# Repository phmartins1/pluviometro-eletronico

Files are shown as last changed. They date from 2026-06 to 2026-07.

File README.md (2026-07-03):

# Pluviômetro Eletrônico

Projeto de um **pluviômetro eletrônico** utilizando **sensores piezoelétricos**.

* **Hardware**: Circuito elétrico integrado com um microcontrolador ESP32
* **Firmware**: Captura dos dados e transmissão via protocolo MQTT, operando sobre conexão WiFi
* **Nuvem**: Cálculo do volume de chuva (mm e mm/h) a partir do sinal cru

## Estrutura do Repositório

```
pluviometro-eletronico/
├── checkpoints-anteriores/   # Material desenvolvido em checkpoints anteriores (ultrapassado)
├── firmware/                 # Firmware de leitura dos piezos e transmissão de dados (ESP32)
├── hardware/                 # Esquemáticos elétricos do pluviômetro
├── telemetria/               # Simulador da telemetria
├── .gitignore
└── README.md
```

## Arquitetura: mínimo na placa, cálculo na nuvem

A abordagem atual divide o trabalho assim: **a placa só mede, a nuvem interpreta**.

O ESP32 lê os 4 piezos, preenche um buffer de `N` amostras por canal e publica os
buffers **brutos** (tensão em V) junto com o tempo real de coleta e a geometria do
sensor. Ele não calcula integral, mm, mm/h, RMS nem picos. Toda essa interpretação
acontece na nuvem (ThingsBoard / processamento), que guarda o histórico e a forma de
onda completa.

Vantagens:

- **Recalibração livre**: como a nuvem tem o sinal cru de todo o histórico, dá para
  mudar a constante de calibração ou o próprio algoritmo e reavaliar tudo, sem
  reprogramar o sensor.
- **Placa mais simples e econômica**: sem timer, sem acumuladores, sem multiplicação
  por calibração. Entre coletas o ESP poderia até entrar em deep sleep.
- **Flexibilidade**: qualquer métrica nova (filtragem de artefatos, contagem de
  impactos, detecção de eventos) é só uma consulta sobre os dados já guardados.

### O que a placa envia

A cada buffer cheio, o ESP publica um JSON via MQTT:

```json
{
  "ident": "pluviometro_teste",
  "T": 1.395,
  "n": 300,
  "area_maior_cm2": 144.0,
  "area_menor_cm2": 47.6,
  "buf_A0": [0.0, 0.0, 0.142, ...],
  "buf_A1": [...],
  "buf_A2": [...],
  "buf_A3": [...]
}
```

| Campo | O que é |
|---|---|
| `ident` | identificador do device (usado pelo stream flespi -> ThingsBoard) |
| `T` | duração **real** da coleta dos `N` pontos (s), medida com `millis()` |
| `n` | amostras por canal |
| `area_maior_cm2` | área das faces maiores (A0, A2) |
| `area_menor_cm2` | área das faces menores (A1, A3) |
| `buf_A0..buf_A3` | buffers brutos de tensão (V) de cada piezo |

> O payload tem alguns KB (4 buffers de `N` floats). No firmware é preciso aumentar o
> buffer interno do PubSubClient (`setBufferSize`), senão a mensagem é truncada.

## Precisão por área: combinando os 4 piezos

O pluviômetro tem 4 faces piezoelétricas de dois tamanhos:

- Faces **maiores** (A0, A2): 144 cm² cada.
- Faces **menores** (A1, A3): 47,6 cm² cada.
- Área total de captação: `2*144 + 2*47,6 = 383,2 cm²`.

Cada piezo é um coletor de área conhecida. O integral `S` de cada face é proporcional à
quantidade de água que bateu nela, ou seja, proporcional à taxa de chuva **vezes** a
área daquela face. Uma face maior recebe mais gotas e gera um sinal proporcionalmente
maior (no simulador isso aparece como o fator `AREA_MENOR / AREA_MAIOR`, que reduz o
sinal das faces menores na proporção da área).

Para ganhar precisão, a nuvem trata os 4 piezos como **um único coletor maior**: soma os
integrais e divide pela área total. Combinar mais área é o mesmo que ter um pluviômetro
maior, então o ruído estatístico (pouca gota numa janela curta) se cancela e a lâmina
(mm) fica mais estável do que a de um piezo isolado.

Cálculo na nuvem, por reporte:

```
# 1. integral de cada face a partir do buffer (mesma fórmula de antes, agora na nuvem)
S_i = (soma das tensões do buffer_i) * T / n        [V·s]

# 2. combina as 4 faces como um coletor de área total
S_total = S_A0 + S_A1 + S_A2 + S_A3
A_total = 383,2 cm²

# 3. lâmina caída no período (a calibração c embute a área e a sensibilidade)
lamina_mm = c * S_total

# ou, deixando a área explícita (densidade de sinal por área):
densidade   = S_total / A_total        [V·s/cm²]
lamina_mm   = c_area * densidade
```

A ponderação por área é exatamente essa divisão pela área total: as faces maiores pesam
mais, as menores pesam menos, na proporção em que captam chuva. O acumulado (mm) e as
intensidades (mm/h) saem de somar `S_total` sobre diferentes janelas de tempo.

## Simulador

[`telemetria/simulador-telemetria.py`](telemetria/simulador-telemetria.py) reproduz a telemetria da
abordagem atual: gera os buffers brutos dos 4 piezos (com sinal proporcional à área de
cada face) e publica no broker no mesmo formato do firmware. Útil para desenvolver e
testar o processamento na nuvem sem o hardware.

```
pip install paho-mqtt
python simulador-telemetria.py
```

## Segurança

Credenciais sensíveis (Rede WiFi, Broker MQTT) não são incluídas no repositório.

Utilize o arquivo [`firmware/exemplo_secrets.h`](firmware/exemplo_secrets.h) como base para criar seu próprio `secrets.h`.

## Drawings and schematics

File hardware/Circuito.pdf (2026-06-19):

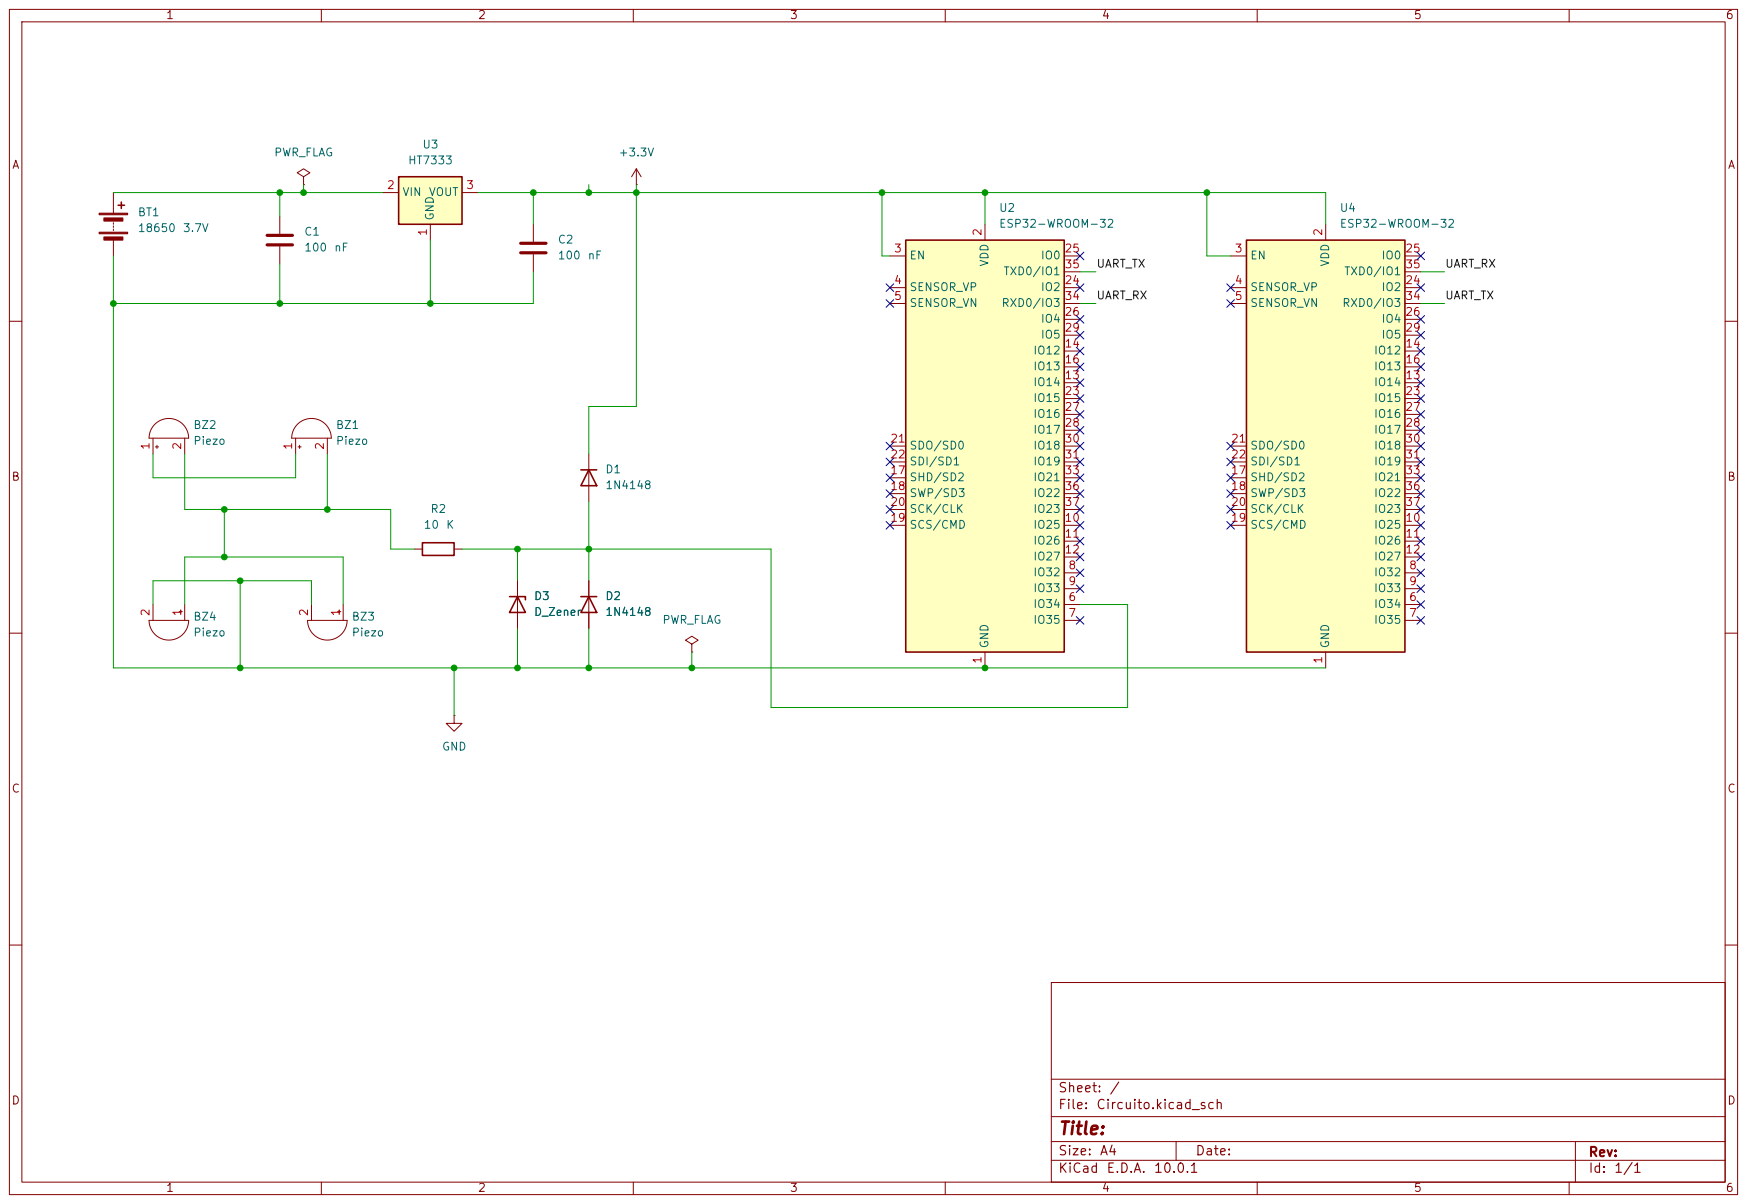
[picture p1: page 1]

Size: A4 | Rev:
KiCad E.D.A. 10.0.1 | Id: 1/1

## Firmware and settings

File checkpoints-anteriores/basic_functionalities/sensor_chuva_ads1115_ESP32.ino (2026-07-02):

/*
   OBJETIVO:
   - Ler tensão do piezo ao longo do tempo
   - Detectar impactos de chuva
   - Medir:
       * Pico de tensão
       * Energia RMS
       * Taxa de impactos
       * Integral do sinal (S) -> base do cálculo de chuva (mm e mm/h)
   - Publicar a telemetria no broker MQTT (ThingsBoard / flespi)

   OBS:
   ligação é single-ended (0V a 3.3V),
   o sinal negativo é cortado pelos diodos.
   detectar PULSOS/IMPACTOS.

   DIVISÃO DE RESPONSABILIDADES (ver calculo_chuva_piezo_thingsboard.md):
   - O ESP32 apenas MEDE: integra o sinal (S, em V·s) e acumula ~10 s.
   - O ThingsBoard INTERPRETA: aplica a constante de calibração c e agrega
     para gerar acumulado (mm), intensidade real (mm/h) e instantânea (mm/h).
   Por isso o ESP NÃO multiplica por c nem calcula mm/h: manda só o S cru.
*/

// Wifi Base
#include <WiFi.h>
// Biblioteca MQTT
#include <PubSubClient.h>
// Montar JSON
#include <ArduinoJson.h>
#include <Wire.h>
#include <Adafruit_ADS1X15.h>
// Configurações (credenciais de WiFi e broker)
#include "secrets.h"

Adafruit_ADS1115 ads;

// CONFIGURAÇÕES

// Pinos I2C no ESP32
#define SDA_PIN 21
#define SCL_PIN 22
#define CHANNEL 0
#define CHANNEL_2 2

const int SAMPLE_RATE = 860;        // máximo ADS1115
const int BUFFER_SIZE = 300;        // ~348 ms de janela (N amostras)
const float THRESHOLD = 0.03;       // 30mV (mais sensível) podemos alterar aqui caso precisarmos de aumentar/diminuir a sensibilidade
const float ADC_LSB = 0.000125;     // GAIN_ONE = 0.125mV/bit
const float NOISE_FLOOR = 0.003;    // abaixo disso é ruído, vira 0

float samplesA0[BUFFER_SIZE];       //Buffer leityra canal 1
float samplesA2[BUFFER_SIZE];       //Buffer leityra canal 2

// Conexões
const unsigned long TIMEOUT_CONEXAO = 20000;
const unsigned long INTERVALO_VERIFICACAO = 10000;
unsigned long ultimaVerificacao = 0;

WiFiClient clienteWiFi;
PubSubClient clienteMQTT(clienteWiFi);

// Intervalo de reporte: acumula ~10 s e publica o S somado (ver doc, seção 7).
const unsigned long INTERVALO_PUBLICACAO = 10000;

// Acumuladores do intervalo de reporte (Entrada A0)
float    S_reportA0        = 0;   // soma dos S de cada janela (V·s) -> principal
uint32_t impactos_reportA0 = 0;   // contagem de impactos no intervalo
float    pico_reportA0     = 0;   // maior tensão no intervalo (diagnóstico)
double   somaQuad_reportA0 = 0;   // soma dos quadrados (para o RMS do intervalo)
uint32_t nAmostras_reportA0 = 0;  // total de amostras lidas no intervalo
unsigned long t_ini_reportA0 = 0; // marca o início do intervalo de reporte


// Acumuladores do intervalo de reporte (Entrada A2)
float    S_reportA2        = 0;   // soma dos S de cada janela (V·s) -> principal
uint32_t impactos_reportA2 = 0;   // contagem de impactos no intervalo
float    pico_reportA2     = 0;   // maior tensão no intervalo (diagnóstico)
double   somaQuad_reportA2 = 0;   // soma dos quadrados (para o RMS do intervalo)
uint32_t nAmostras_reportA2 = 0;  // total de amostras lidas no intervalo
unsigned long t_ini_reportA2 = 0; // marca o início do intervalo de reporte


// FUNÇÕES

// Calcula RMS (Root Mean Square / valor quadrático médio)
// Mede a energia média do sinal na janela de amostras.
// Útil para estimar intensidade geral da chuva:
// - RMS baixo = pouco impacto / chuva fraca
// - RMS alto = muitos impactos / chuva forte
//
// Etapas:
// 1. Eleva cada amostra ao quadrado
// 2. Soma tudo
// 3. Divide pelo número de amostras
// 4. Aplica raiz quadrada para voltar à unidade em volts
// Calcula RMS
float calculateRMS(float *buffer, int size) {
  double sum = 0;

  for (int i = 0; i < size; i++) {
    sum += buffer[i] * buffer[i];
  }

  return sqrt(sum / size);
}

// Pico máximo
// Calcula o pico máximo de tensão na janela de amostras
// Mede o maior valor detectado pelo sensor no período analisado.
// Útil para identificar o impacto mais forte (ex: gota maior ou batida mais intensa).
//
// Etapas:
// 1. Percorre todas as amostras
// 2. Compara cada valor com o maior já encontrado
// 3. Atualiza se encontrar um valor maior
// 4. Retorna o maior pico de tensão registrado
float calculatePeak(float *buffer, int size) {
  float peak = 0;

  for (int i = 0; i < size; i++) {
    if (buffer[i] > peak) {
      peak = buffer[i];
    }
  }

  return peak;
}

// Soma linear das tensões da janela (Σ|vi|).
// É a base do integral S: somaV / N é a tensão média, e multiplicada pelo
// tempo da janela vira a "área" sob o sinal (V·s).
float sumVoltage(float *buffer, int size) {
  float soma = 0;

  for (int i = 0; i < size; i++) {
    soma += buffer[i];
  }

  return soma;
}

/// Conta quantos impactos (gotas/pulsos) ocorreram na janela de amostras.
// Um impacto é registrado quando o sinal ultrapassa o threshold definido.
//
// Cooldown (período morto):
// Após detectar um impacto, o sistema ignora algumas leituras por alguns ms
// para evitar contar várias oscilações da mesma gota como impactos diferentes.
//
// Etapas:
// 1. Percorre todas as amostras
// 2. Verifica se está em cooldown
// 3. Se estiver, ignora a leitura
// 4. Se o valor passar do threshold, conta um novo impacto
// 5. Ativa cooldown para evitar múltiplas contagens do mesmo evento
int countImpacts(float *buffer, int size, float threshold) {
  int count = 0;
  int cooldown = 0;

  for (int i = 0; i < size; i++) {

    // Ignora leituras durante período morto
    if (cooldown > 0) {
      cooldown--;
      continue;
    }

    // Novo impacto
    if (buffer[i] > threshold) {
      count++;
      cooldown = 8; // ~9 ms em 860 SPS
    }
  }

  return count;
}

// CONEXÃO WIFI
bool conectarWiFi()
{
  Serial.print("Conectando à rede: ");
  Serial.println(WIFI_SSID);

  WiFi.mode(WIFI_STA);
  WiFi.begin(WIFI_SSID, WIFI_PASSWORD);

  unsigned long inicio = millis();
  while (WiFi.status() != WL_CONNECTED)
  {
    if (millis() - inicio > TIMEOUT_CONEXAO)
    {
      Serial.println("\nFalha: tempo de conexão esgotado.");
      return false;
    }
    delay(500);
    Serial.print(".");
  }

  Serial.println("\nConexão estabelecida!");
  Serial.print("Endereço IP: ");
  Serial.println(WiFi.localIP());
  Serial.print("RSSI (intensidade do sinal): ");
  Serial.print(WiFi.RSSI());
  Serial.println(" dBm");
  return true;
}

// CONEXÃO BROKER MQTT
void conectarBrokerMQTT()
{
  if (WiFi.status() != WL_CONNECTED)
    return;

  Serial.println("Conectando ao Broker MQTT...");

  unsigned long inicio = millis();
  while (!clienteMQTT.connected())
  {
    if (millis() - inicio > TIMEOUT_CONEXAO)
    {
      Serial.println("\nFalha: tempo de conexão ao Broker MQTT esgotado.");
      return;
    }

    char IDCliente[50];
    sprintf(IDCliente, "PEC-Pluviometro-%06X", (uint32_t)ESP.getEfuseMac());

    if (clienteMQTT.connect(IDCliente, TOKEN_BROKER, ""))
    {
      Serial.println("Conectado ao Broker MQTT.");
      return;
    }
    else
    {
      Serial.print("Falha, rc=");
      Serial.println(clienteMQTT.state()); // diagnostico de falha
      delay(2000);
    }
  }
}

// verificar e reconectar se necessário
void verificarConexao()
{
  if (WiFi.status() != WL_CONNECTED)
  {
    Serial.println("Conexão WiFi perdida. Tentando reconectar...");
    WiFi.disconnect();
    conectarWiFi();
  }
  else
  {
    Serial.print("Wi-Fi ativo | IP: ");
    Serial.print(WiFi.localIP());
    Serial.print(" | RSSI: ");
    Serial.print(WiFi.RSSI());
    Serial.println(" dBm");
  }

  if (!clienteMQTT.connected())
  {
    Serial.println("Conexão ao Broker MQTT perdida. Tentando reconectar...");
    clienteMQTT.disconnect();
    conectarBrokerMQTT();
  }
}

// Monta e publica a telemetria do intervalo de reporte.
// Campos (ver doc, seção 4):
//   S        -> integral acumulado do intervalo (V·s)  [PRINCIPAL]
//   T        -> duração real do intervalo (s)
//   impactos -> contagem de impactos no intervalo
//   pico     -> maior tensão no intervalo (diagnóstico)
//   rms      -> RMS do sinal no intervalo (diagnóstico)
// IMPORTANTE: envia o INCREMENTO do intervalo (não um total que só cresce),
// para o SUM do ThingsBoard funcionar direto.
void publicarTelemetria(float S, float T, uint32_t impactos, float pico, float rms)
{
  JsonDocument doc;

  // O 'ident' e obrigatorio: o stream flespi -> ThingsBoard usa ele para
  // identificar o device. Sem ident a mensagem nao chega no ThingsBoard.
  doc["ident"] = "pluviometro_teste";
  doc["S"] = S;
  doc["T"] = T;
  doc["impactos"] = impactos;
  doc["pico"] = pico;
  doc["rms"] = rms;

  String payload;
  serializeJson(doc, payload);

  if (clienteMQTT.connected())
  {
    bool publicado = clienteMQTT.publish(TOPICO_MQTT, payload.c_str());
    if (publicado)
      Serial.println("Publicado: " + payload);
    else
      Serial.println("Falha ao publicar");
  }
  else
  {
    Serial.println("Sem conexão MQTT, telemetria não enviada: " + payload);
  }
}

// SETUP
void setup() {
  Serial.begin(115200);
  delay(1000);

  Wire.begin(SDA_PIN, SCL_PIN);

  if (!ads.begin()) {
    Serial.println("ERRO: ADS1115 não encontrado!");
    while (1);
  }

  ads.setGain(GAIN_ONE);                  // até 4.096V
  ads.setDataRate(RATE_ADS1115_860SPS);  // máxima velocidade

  Serial.println("\nInicializando módulo Wi-Fi");
  conectarWiFi();

  clienteMQTT.setServer(BROKER_MQTT, PORTA_MQTT);
  conectarBrokerMQTT();

  Serial.println("Sistema iniciado");
  t_ini_reportA0 = millis();
  t_ini_reportA2 = millis();
}

// LOOP
void loop() {

  // --- coleta uma janela cronometrada de N amostras ---
  unsigned long t0 = millis();
  for (int i = 0; i < BUFFER_SIZE; i++) {

    //int16_t raw = ads.readADC_SingleEnded(CHANNEL);
    int16_t rawA0 = ads.readADC_SingleEnded(CHANNEL);
    int16_t rawA2 = ads.readADC_SingleEnded(CHANNEL_2);

    // Converte para volts
    //float voltage = raw * ADC_LSB;
    float voltageA0 = rawA0 * ADC_LSB;
    float voltageA2 = rawA2 * ADC_LSB;


    // Remove ruído muito baixo
    //if (voltage < NOISE_FLOOR) voltage = 0;
    if (voltageA0 < NOISE_FLOOR) voltageA0 = 0;
    if (voltageA2 < NOISE_FLOOR) voltageA2 = 0;

    //samples[i] = voltage;
    samplesA0[i] = voltageA0;
    samplesA2[i] = voltageA2;

    // ADS1115 já limita pela taxa interna
    delay(1);
  }
  float T_janela = (millis() - t0) / 1000.0;  // duração REAL da janela (s)

  // --- análises da janela ---
  //float somaV = sumVoltage(samples, BUFFER_SIZE);
  //float peak = calculatePeak(samples, BUFFER_SIZE);
  //int impacts = countImpacts(samples, BUFFER_SIZE, THRESHOLD);
  float peakA0 = calculatePeak(samplesA0, BUFFER_SIZE);
  float peakA2 = calculatePeak(samplesA2, BUFFER_SIZE);

  int impactsA0 = countImpacts(samplesA0, BUFFER_SIZE, THRESHOLD);
  int impactsA2 = countImpacts(samplesA2, BUFFER_SIZE, THRESHOLD);

  float somaVA0 = sumVoltage(samplesA0, BUFFER_SIZE);
  float somaVA2 = sumVoltage(samplesA2, BUFFER_SIZE);

  // Integral da janela: S = (tensão média) * tempo da janela = somaV * T / N
  //float S_janela = somaV * T_janela / BUFFER_SIZE;
  float S_janelaA0 = somaVA0 * T_janela / BUFFER_SIZE;
  float S_janelaA2 = somaVA2 * T_janela / BUFFER_SIZE;

  // --- acúmulo no intervalo de reporte ---
  S_reportA0 += S_janelaA0;
  S_reportA2 += S_janelaA2;

  impactos_reportA0 += impactsA0;
  impactos_reportA2 += impactsA2;

  if (peakA0 > pico_reportA0) pico_reportA0 = peakA0;
  for (int i = 0; i < BUFFER_SIZE; i++) {
    somaQuad_reportA0 += (double)samplesA0[i] * samplesA0[i];
  }
  nAmostras_reportA0 += BUFFER_SIZE;

  if (peakA2 > pico_reportA2) pico_reportA2 = peakA2;
  for (int i = 0; i < BUFFER_SIZE; i++) {
    somaQuad_reportA2 += (double)samplesA2[i] * samplesA2[i];
  }
  nAmostras_reportA2 += BUFFER_SIZE;

  // Classificação de chuva (exemplo simples; refinar futuramente)
  const char* chuva;
  int impacts = (impactsA0 + impactsA2);
  if (impacts < 1)        chuva = "Sem Chuva";
  else if (impacts < 8)   chuva = "Chuva Fraca";
  else if (impacts < 20)  chuva = "Chuva Moderada";
  else                    chuva = "Chuva Forte";

  // SERIAL MONITOR (diagnóstico da janela)
  Serial.println("--------------------------------");

  Serial.print("Pico Piezo 1: ");      Serial.print(peakA0, 4);      Serial.println(" V");
  Serial.print("Pico Piezo 2: ");      Serial.print(peakA2, 4);      Serial.println(" V");


  Serial.print("Impactos Somados (Piezo 1 + Piezo 2): ");  Serial.println(impacts);

  Serial.print("S janela Piezo 1: ");  Serial.print(S_janelaA0, 6);  Serial.println(" V.s");
  Serial.print("S janela Piezo 2: ");  Serial.print(S_janelaA2, 6);  Serial.println(" V.s");

  Serial.print("Status: ");    Serial.println(chuva);

  // --- a cada INTERVALO_PUBLICACAO, publica o acumulado e zera ---
  if (millis() - t_ini_reportA0 >= INTERVALO_PUBLICACAO) {
    float T_reportA0 = (millis() - t_ini_reportA0) / 1000.0;
    float rms_reportA0 = nAmostras_reportA0 > 0
                         ? sqrt(somaQuad_reportA0 / nAmostras_reportA0)
                         : 0;
               
    publicarTelemetria(S_reportA0, T_reportA0, impactos_reportA0, pico_reportA0, rms_reportA0);
    

    // zera os acumuladores do próximo intervalo
    S_reportA0 = 0;
    impactos_reportA0 = 0;
    pico_reportA0 = 0;
    somaQuad_reportA0 = 0;
    nAmostras_reportA0 = 0;
    t_ini_reportA0 = millis();

  }

  if (millis() - t_ini_reportA2 >= INTERVALO_PUBLICACAO) {
    float T_reportA2 = (millis() - t_ini_reportA2) / 1000.0;
    float rms_reportA2 = nAmostras_reportA2 > 0
                         ? sqrt(somaQuad_reportA2 / nAmostras_reportA2)
                         : 0;

    publicarTelemetria(S_reportA2, T_reportA2, impactos_reportA2, pico_reportA2, rms_reportA2);

    
    S_reportA2 = 0;
    impactos_reportA2 = 0;
    pico_reportA2 = 0;
    somaQuad_reportA2 = 0;
    nAmostras_reportA2 = 0;
    t_ini_reportA2 = millis();
  }     

  // Reconexão periódica (não bloqueia a coleta)
  if (millis() - ultimaVerificacao >= INTERVALO_VERIFICACAO) {
    ultimaVerificacao = millis();
    verificarConexao();
  }

  clienteMQTT.loop();
}

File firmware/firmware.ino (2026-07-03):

/*
   OBJETIVO: O ESP32 realiza as medições brutas e envia via MQTT.
   Os cálculos matemáticos e geração do volume total ocorrem na Rule Chain.
*/

// Wifi Base
#include <WiFi.h>
// Biblioteca MQTT
#include <PubSubClient.h>
// Montar JSON
#include <ArduinoJson.h>
#include <Wire.h>
#include <Adafruit_ADS1X15.h>
// Configurações (credenciais de WiFi e broker)
#include "secrets.h"

Adafruit_ADS1115 ads;

// CONFIGURAÇÕES
#define SDA_PIN 21
#define SCL_PIN 22
#define CHANNEL 0
#define CHANNEL_1 1
#define CHANNEL_2 2
#define CHANNEL_3 3

const float JANELA_SEGUNDOS = 5.0;
const int   BUFFER_SIZE = 300;        // N amostras por canal antes de publicar
const float ADC_LSB     = 0.000125;   // GAIN_ONE = 0,125 mV/bit
const float NOISE_FLOOR = 0.003;      // abaixo disso é ruído, vira 0 (V)


// Buffers de leitura (tensão em V)
float samples_PiezoA0[BUFFER_SIZE];
float samples_PiezoA1[BUFFER_SIZE];
float samples_PiezoA2[BUFFER_SIZE];
float samples_PiezoA3[BUFFER_SIZE];

const uint16_t MQTT_BUFFER_SIZE = 20480;

// Conexões
const unsigned long TIMEOUT_CONEXAO = 20000;
const unsigned long INTERVALO_VERIFICACAO = 10000;
unsigned long ultimaVerificacao = 0;

WiFiClient clienteWiFi;
PubSubClient clienteMQTT(clienteWiFi);

bool conectarWiFi() {
  Serial.print("Conectando à rede: ");
  Serial.println(WIFI_SSID);
  WiFi.mode(WIFI_STA);
  WiFi.begin(WIFI_SSID, WIFI_PASSWORD);

  unsigned long inicio = millis();
  while (WiFi.status() != WL_CONNECTED) {
    if (millis() - inicio > TIMEOUT_CONEXAO) {
      Serial.println("\nFalha: tempo de conexão esgotado.");
      return false;
    }
    delay(500);
    Serial.print(".");
  }
  Serial.println("\nConexão estabelecida!");
  return true;
}

void conectarBrokerMQTT() {
  if (WiFi.status() != WL_CONNECTED) return;
  Serial.println("Conectando ao ThingsBoard via MQTT...");

  unsigned long inicio = millis();
  while (!clienteMQTT.connected()) {
    if (millis() - inicio > TIMEOUT_CONEXAO) {
      Serial.println("\nFalha: tempo de conexão esgotado.");
      return;
    }

    char IDCliente[50];
    sprintf(IDCliente, "ESP32-Pluviometro-%06X", (uint32_t)ESP.getEfuseMac());

    if (clienteMQTT.connect(IDCliente, TOKEN_BROKER, "")) {
      Serial.println("Conectado ao ThingsBoard com sucesso!");
      return;
    } else {
      Serial.print("Falha na conexão, rc=");
      Serial.println(clienteMQTT.state());
      delay(2000);
    }
  }
}

void verificarConexao() {
  if (WiFi.status() != WL_CONNECTED) {
    WiFi.disconnect();
    conectarWiFi();
  }
  if (!clienteMQTT.connected()) {
    conectarBrokerMQTT();
  }
}

void publicarBuffers(float T) {
  JsonDocument doc;
  doc["T"] = T;
  doc["n"] = BUFFER_SIZE;

  JsonArray a0 = doc["buf_A0"].to<JsonArray>();
  JsonArray a1 = doc["buf_A1"].to<JsonArray>();
  JsonArray a2 = doc["buf_A2"].to<JsonArray>();
  JsonArray a3 = doc["buf_A3"].to<JsonArray>();

  for (int i = 0; i < BUFFER_SIZE; i++) {
    a0.add(serialized(String(samples_PiezoA0[i], 4)));
    a1.add(serialized(String(samples_PiezoA1[i], 4)));
    a2.add(serialized(String(samples_PiezoA2[i], 4)));
    a3.add(serialized(String(samples_PiezoA3[i], 4)));
  }

  String payload;
  serializeJson(doc, payload);

  if (clienteMQTT.connected()) {
    bool publicado = clienteMQTT.publish(TOPICO_MQTT, payload.c_str());
    if (publicado) {
      Serial.printf("Enviado: T=%.3f s | %u bytes\n", T, (unsigned)payload.length());
    } else {
      Serial.printf("Falha ao enviar. %u bytes\n", (unsigned)payload.length());
    }
  } else {
    Serial.println("Sem conexão MQTT. Dados perdidos.");
  }
}

void setup() {
  Serial.begin(115200);
  delay(1000);
  Wire.begin(SDA_PIN, SCL_PIN);
  Wire.setClock(400000);

  if (!ads.begin()) {
     Serial.println("ERRO: ADS1115 não encontrado!");
     while (1);
  }

  ads.setGain(GAIN_ONE);          
  ads.setDataRate(RATE_ADS1115_860SPS);  

  conectarWiFi();
  clienteMQTT.setBufferSize(MQTT_BUFFER_SIZE);
  clienteMQTT.setServer(BROKER_MQTT, PORTA_MQTT);
  conectarBrokerMQTT();

  Serial.println("Sistema Pronto.");
}

void loop() {
  unsigned long t0 = micros();
  
  // 5 segundos / 300 amostras = 16666 us por ciclo
  const uint32_t INTERVALO_US = (uint32_t)(JANELA_SEGUNDOS * 1000000.0 / BUFFER_SIZE);
  uint32_t proximaLeitura = micros();

  for (int i = 0; i < BUFFER_SIZE; ) {
    if ((int32_t)(micros() - proximaLeitura) >= 0) {
      
      // Realiza a leitura sequencial nos 4 canais
      int16_t raw_PiezoA0 = ads.readADC_SingleEnded(CHANNEL);
      int16_t raw_PiezoA1 = ads.readADC_SingleEnded(CHANNEL_1);
      int16_t raw_PiezoA2 = ads.readADC_SingleEnded(CHANNEL_2);
      int16_t raw_PiezoA3 = ads.readADC_SingleEnded(CHANNEL_3);

      float v0 = raw_PiezoA0 * ADC_LSB;
      float v1 = raw_PiezoA1 * ADC_LSB;
      float v2 = raw_PiezoA2 * ADC_LSB;
      float v3 = raw_PiezoA3 * ADC_LSB;

      samples_PiezoA0[i] = (v0 < NOISE_FLOOR) ? 0.0f : v0;
      samples_PiezoA1[i] = (v1 < NOISE_FLOOR) ? 0.0f : v1;
      samples_PiezoA2[i] = (v2 < NOISE_FLOOR) ? 0.0f : v2;
      samples_PiezoA3[i] = (v3 < NOISE_FLOOR) ? 0.0f : v3;

      i++;
      proximaLeitura += INTERVALO_US;
    }

    clienteMQTT.loop();
    yield();
  }

  float T = (micros() - t0) / 1000000.0f; 

  // Validação da integridade temporal da janela
  if (T > JANELA_SEGUNDOS * 1.1f) { // Margem de 10% de estouro tolerada
    Serial.printf("Coleta descartada por estouro de tempo: %.3f s\n", T);
  } else {
    publicarBuffers(T);
  }

  if (millis() - ultimaVerificacao >= INTERVALO_VERIFICACAO) {
    ultimaVerificacao = millis();
    verificarConexao();
  }
  clienteMQTT.loop();
}

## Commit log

2026-05-05 Adiciona módulo de detecção de chuva com ADS1115
2026-05-08 adiciona esquemático eletrico
    [Circuito.kicad_pcb, Circuito.kicad_sch]
2026-05-18 conexão com broker mqtt + configuração sigilosa
    [conexao_wifi_basica.ino]
2026-05-18 adição de readme básico
2026-05-22 Add files via upload
    Implementa cálculo de economia de bateria
2026-06-05 transformando payload para JSON
2026-06-07 refactor: enhance sensor_chuva_ads1115.ino and simulador_telemetria.py for improved telemetry data handling and MQTT integration
2026-06-11 Update sensor_chuva_ads1115_ESP32.ino
    Double Pin Analogic
2026-06-18 Create Code Sensor_chuva_ads1115_4Piezos
    Código coletando dados de 4 piezos.
2026-06-19 circuito modificado - 2x ESP32 com UART, remove ADS1115
    [Circuito.kicad_sch]
2026-06-25 Refactor pluviômetro: migrate to cloud-based calculations, update README and restructure code
    - Updated README.md to reflect new architecture: ESP32 only measures, cloud handles calculations.
    - Removed old firmware (Sensor_chuva_ads1115_4Piezos) and added new version (Sensor_chuva_ads1115_4Piezos_V2.ino) that sends raw data to the cloud.
    - Introduced new telemetry simulator (simulador_telemetria_v2.py) for testing cloud processing.
    - Enhanced MQTT payload structure to include geometry and raw buffers for improved accuracy in cloud calculations.
